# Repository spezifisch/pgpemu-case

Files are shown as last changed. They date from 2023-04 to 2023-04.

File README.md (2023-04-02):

# pgpemu gadget

A portable [pgpemu](https://github.com/spezifisch/pgpemu) gadget with >40h battery life and charger.

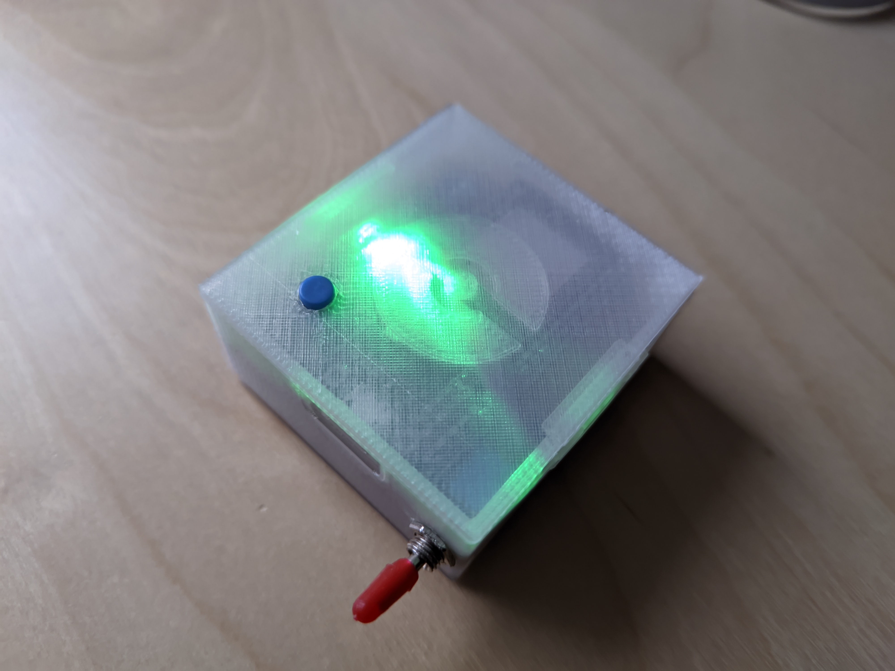
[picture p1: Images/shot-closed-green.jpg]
A 3D printed gadget with translucent plastic illuminated with a green LED


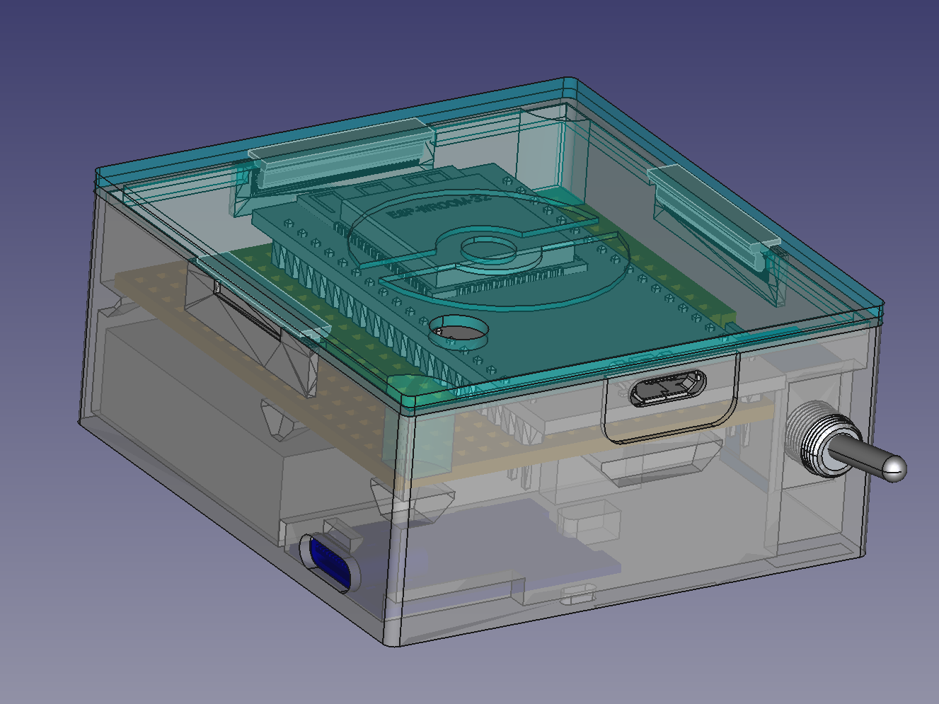
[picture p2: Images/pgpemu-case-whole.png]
3D model of the gadget in FreeCAD


## Usage

You can find the STL files in the `Output` directory.

When printing the bottom part make sure your slicer doesn't remove the thin wall around the ESP32 board's Micro USB port.

My print settings: 0.2mm layer height, 20% infill, transparent PLA.

See assembly notes at the end of this document.

## Development

Requirements:

- FreeCAD 0.20+
- [Assembly4](https://github.com/Zolko-123/FreeCAD_Assembly4)

The main file is `pgpemu_case.FCStd`.

### BOM

- ESP32 board: [ESP32 NODEMCU Module WiFi Development Board with CP2102](https://www.azdelivery.de/en/collections/nodemcu/products/esp32-developmentboard)
- Charger: [USB-C 5V 1A TP4056 Lithium Battery Charger Module](https://aliexpress.com/item/1005004654476348.html)
- LiPo battery: [EEMB 3.7V Lipo Battery 1800mAh 963450](https://www.aliexpress.com/item/1005003318811101.html) (make sure to get a good one with a protection circuit)
- generic toggle switch, 5mm RGB LED + resistors, push button with extension cap, standard silicon diode, 10µF electrolytic capacitor (on the perfboard, after the diode), 10µF SMD 0805 ceramic capacitor (directly on the ESP32 module between its power and ground pins)

## Perfboard

Here are some notes if you're interested to do a similar board. Drop me a mail and I will make you a schematic if you need it.

### LiPo Safety

The first **important** message is: **Do not charge the battery while the device is turned on!** You need extra circuitry to do it safely, which I haven't included because *in my use case* it's not something that I need to do. The device will not explode immediately (hopefully) but this is bad practice, see the reference links below. I see many projects in the wild doing this haphazardly and using LiPo batteries unsafely without knowing better. Be smart and consider using the resources below if you really need this feature. FYI if you see a project that doesn't address this they could be skimping on safety.

Here are some very important considerations when using a LiPo charger:

- <https://emariete.com/en/co2-meter-with-battery-well-done/>
- <https://www.best-microcontroller-projects.com/tp4056.html>
- <https://www.best-microcontroller-projects.com/dw01a.html>

### Supply

The ESP32 has an operating range from 3.0V - 3.6V (see [datasheet p.46](https://www.espressif.com/sites/default/files/documentation/esp32_datasheet_en.pdf)).

The LiPo battery that I chose has a safety circuit which ensures the voltage is >=3.0V and <=4.28V (see [datasheet section 6.1.0](https://ru.eemb.com/public/Download/Rechargeable-Lithium-Battery/Li-Polymer-Battery/Standard-Version/LP963450.pdf)) but the TP4056 charger only charges until 4.2V anyway. Also note that we're charging with 1A and the battery supports this according to the datasheet.

Now I considered generating the ESP32's voltage using either a boost regulator (battery -> boost 5V -> 3.3V with LDO on the ESP32 board), a modern LDO with 0.3V dropout voltage directly (battery -> LDO 3.3V) or just using a standard silicon diode I had lying around anyway to get the battery's range into the ESP32's range (battery -> diode drops 0.7V -> ESP32).

I went with the diode to reduce part count so I get between 2.3V and 3.5V which is safe for the ESP32. I haven't had any issues with this but in any case I added the mentioned 10µF caps.

Note that while you *can't* have the device switched on while charging, you *can* connect the ESP32's Micro USB while charging with the switch in the *off* position. Looking at the [ESP32 board schematic](https://cdn.shopify.com/s/files/1/1509/1638/files/ESP-32_NodeMCU_Developmentboard_Schematic_korr.pdf) the `AMS1117` output would be connected with your diode's cathode so you won't get backward currents into the battery or USB port.

## Assembly

At the bottom the TP4056 is tied down using a cable tie (otherwise USB-C plug action would be quite harsh on it). I isolated it sparing the LEDs for good measure.

The battery is glued to the bottom with a small piece of adhesive tape to keep it from flapping in the breeze. I also added a small piece of foam above the battery (not pictured) and some isolating tape covering the pointy parts of the board.

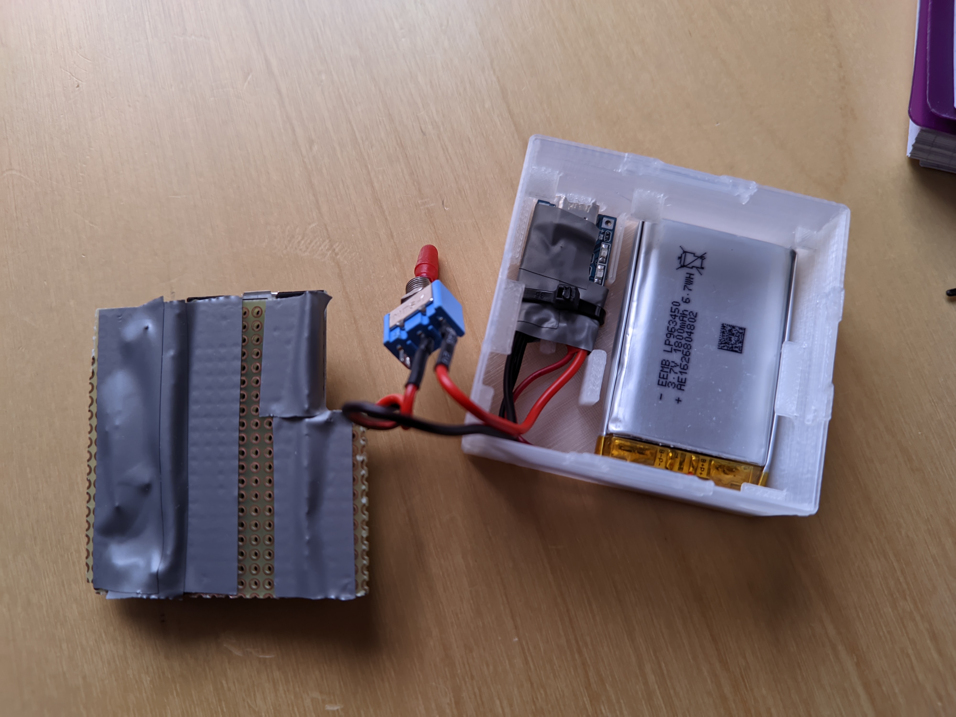
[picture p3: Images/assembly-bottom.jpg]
assembly bottom


The perfboard rests on top of that on the small holders at the sides.

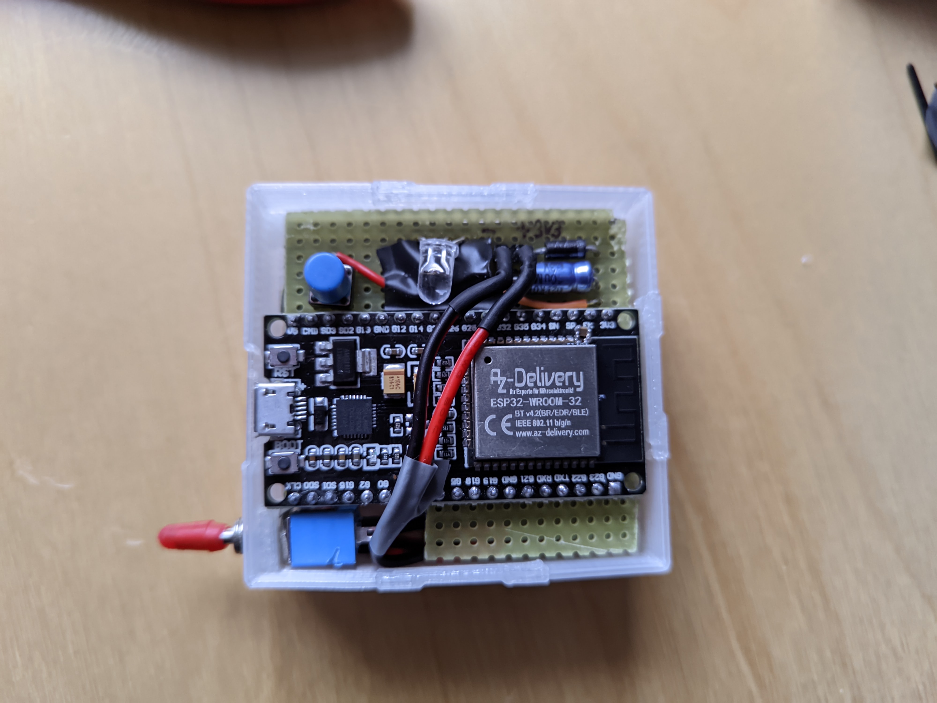
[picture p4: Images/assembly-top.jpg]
assembly top


The finished device, charging (while switched off, of course).

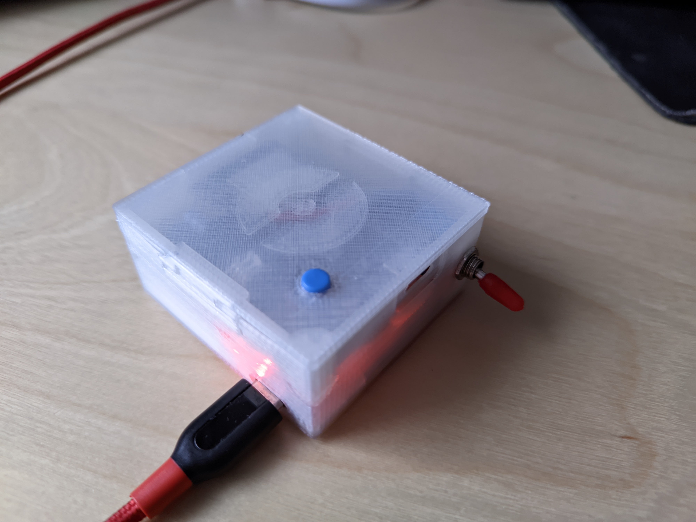
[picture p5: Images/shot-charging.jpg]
charging and glowing red with USB-C plugged in


Micro USB closeup: Access to serial console and bootloader.

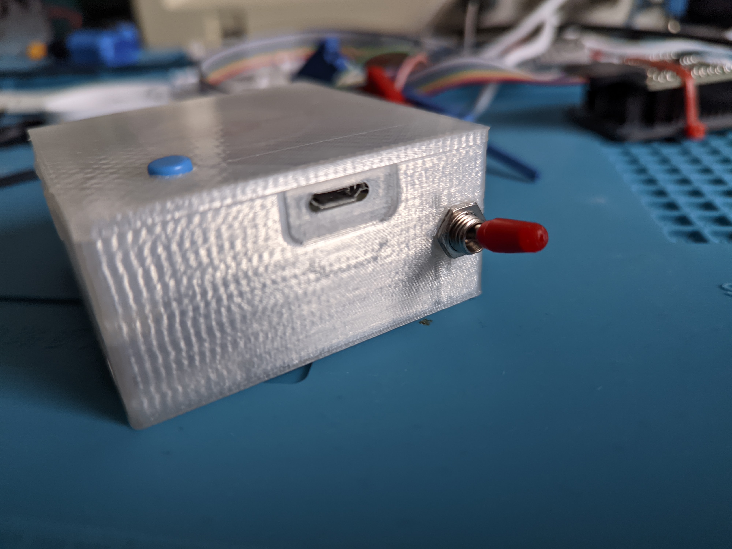
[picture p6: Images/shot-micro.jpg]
Micro USB port


USB-C closeup: Charger access.

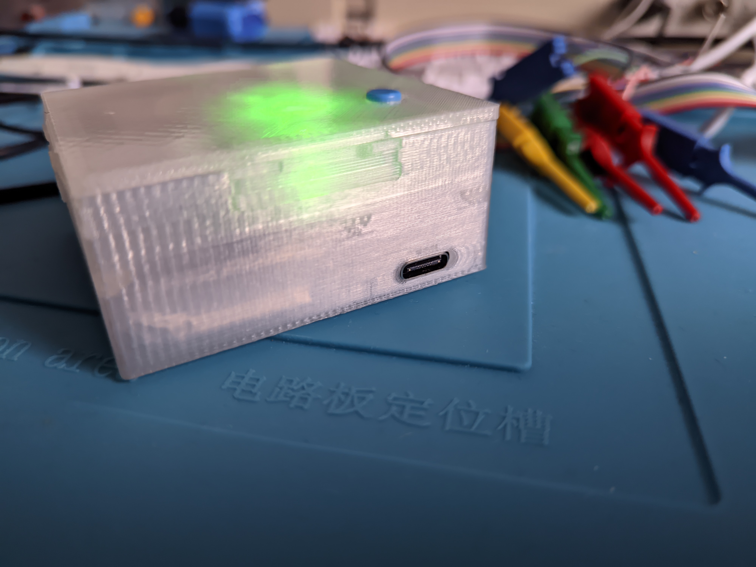
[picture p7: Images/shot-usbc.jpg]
USB-C port


## License

Unless otherwise stated my work in this repository is [CC BY-NC-SA 4.0](https://creativecommons.org/licenses/by-nc-sa/4.0/).

## Attributions

The following 3rd party parts with their own licenses are included.

### `Parts/PerfBoard`

I included the PerfBoard generator source for OpenSCAD with my settings, original:

> This thing was created by Thingiverse user Chunkmunk01, and is licensed under cc.

<https://www.thingiverse.com/thing:2054310>

### `Parts/PinHeader`

I included the PinHeader generator source for OpenSCAD with my settings, original:

> This thing was created by Thingiverse user karfes, and is licensed under cc.

<https://www.thingiverse.com/thing:2051023>

### `Parts/ESP32 DevKit C.FCStd`

ESP32 module and Micro USB port are from:

```text
ESP-WROOM-32

Raphael F. Martins
February 25th, 2020
WROOM-32 FEATURE
SW2018
```

<https://grabcad.com/library/esp-wroom-32-2>

### `Parts/TP4056 battery charger USB-C.*`

USB port is from:

> This thing was created by Thingiverse user Legacy_Micro, and is licensed under cc.

<https://www.thingiverse.com/thing:5745963>

### `Parts/spdt-print-toggle-switch`

Source:

```text
SPDT print toggle switch - PCB Mount

Chrismettal - Binary-6
February 19th, 2022
```

<https://grabcad.com/library/spdt-print-toggle-switch-pcb-mount-1>

### `Parts/Lid Hook.FCStd` and Bottom Receptacle

Source:

```text
ESP32 DevKit Case
by bkgoodman January 25, 2020
```

<https://www.thingiverse.com/thing:4125952>

As used in:

```text
ESP32 DevKit Case Wroom az-delivery 38 PIN
by tispokes April 21, 2022
```

<https://www.thingiverse.com/thing:5361695>

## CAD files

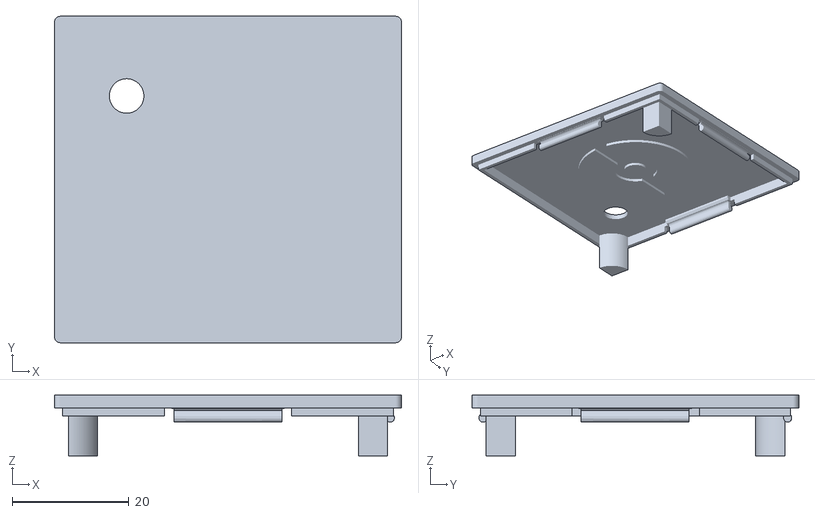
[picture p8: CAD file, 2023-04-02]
Output/pgpemu_case-ModelCase Lid.stl
59.4 x 55.9 x 10.4

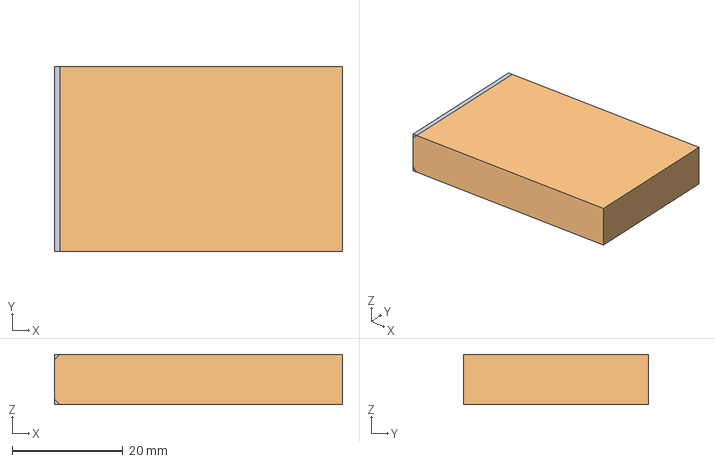
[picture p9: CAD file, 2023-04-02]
Parts/LiPo EEMB 963450.FCStd
52.0 x 33.4 x 9.10 mm

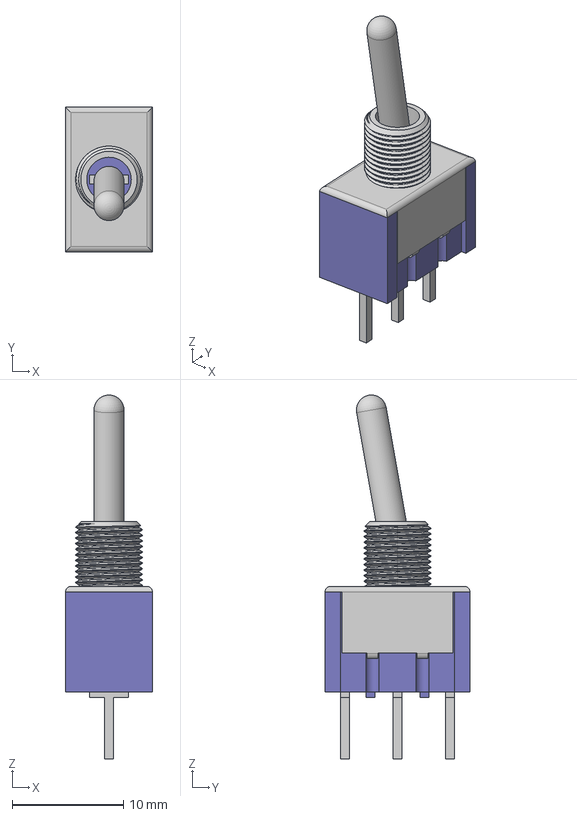
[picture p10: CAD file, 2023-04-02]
Parts/spdt-print-toggle-switch/SPDT-Print-Switch.step
7.80 x 13.0 x 32.7 mm
Plastic_Housing
Pin2
Pin1
Pin3
Shield
Shaft

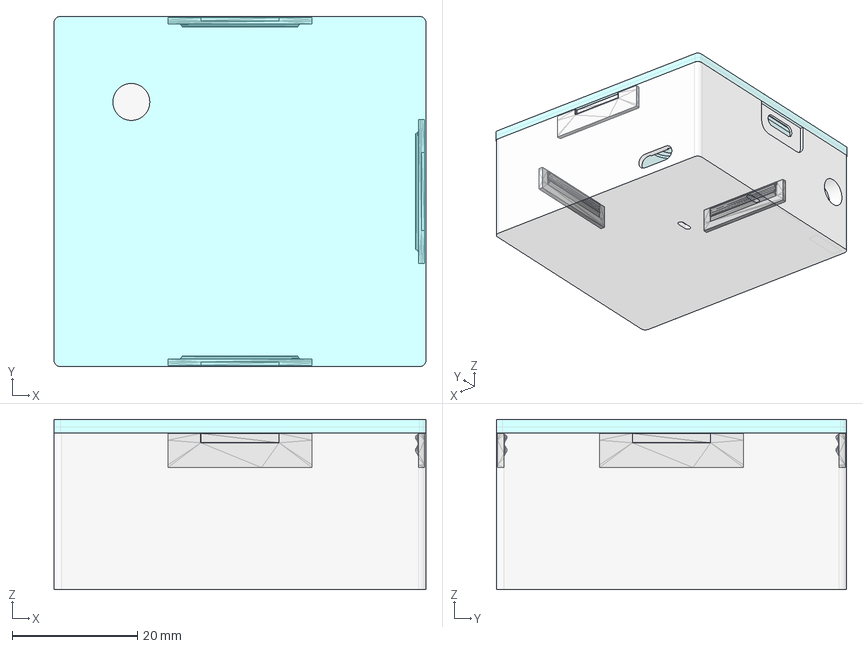
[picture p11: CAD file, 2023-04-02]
pgpemu_case.FCStd
59.4 x 55.9 x 27.2 mm
Lid Receptacle001
Lid Receptacle002
Lid Receptacle003
Lid Body

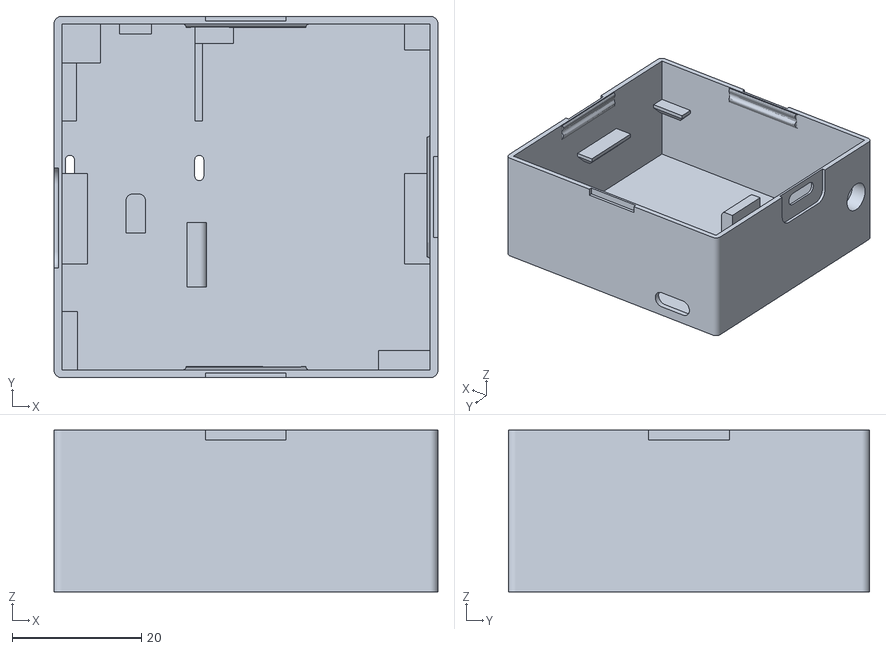
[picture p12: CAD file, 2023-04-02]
Output/pgpemu_case-ModelCase Bottom.stl
59.4 x 55.9 x 25.0

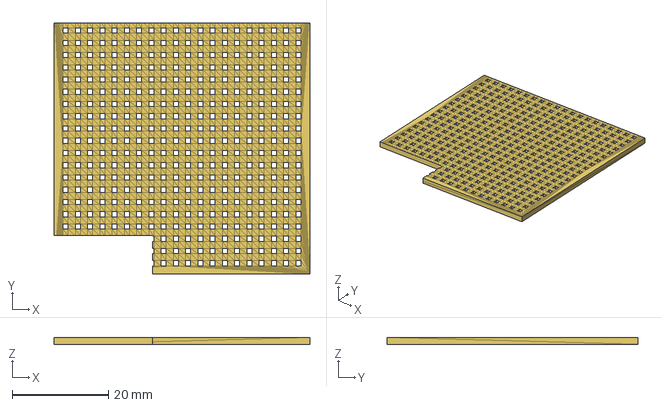
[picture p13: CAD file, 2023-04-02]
Parts/PerfBoard.FCStd
53.1 x 52.0 x 1.50 mm

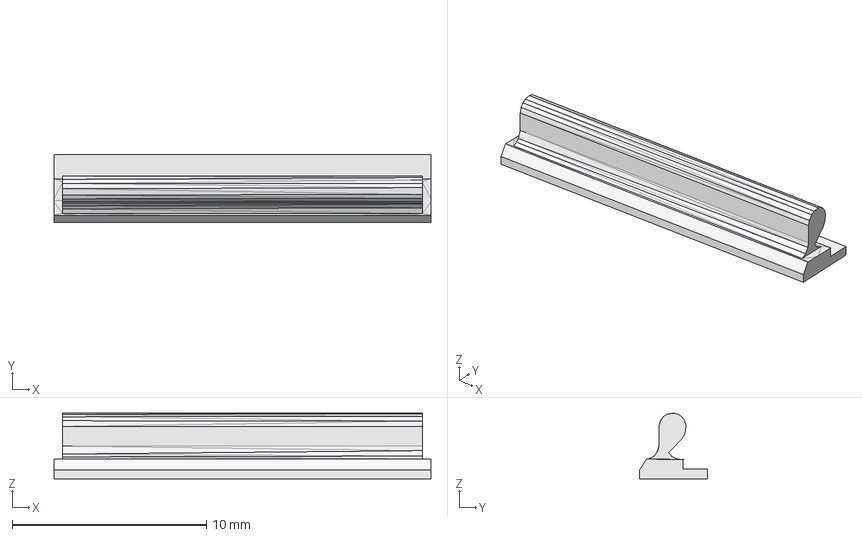
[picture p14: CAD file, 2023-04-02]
Parts/Lid Hook.FCStd
19.4 x 3.50 x 3.38 mm

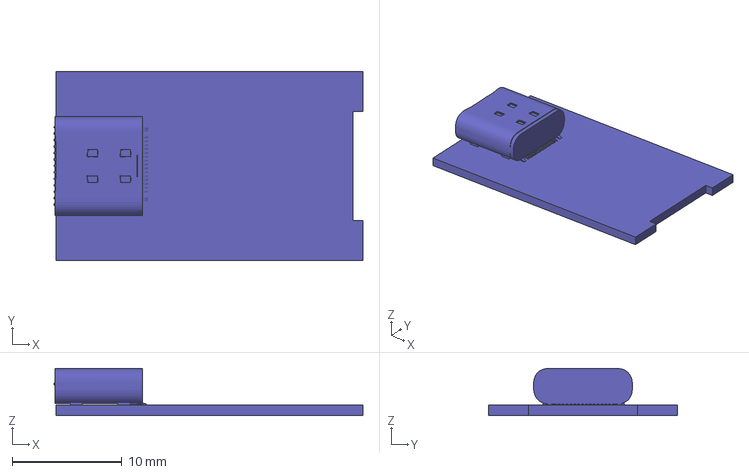
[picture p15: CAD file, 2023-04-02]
Parts/TP4056 battery charger USB-C.FCStd
28.1 x 17.2 x 4.30 mm

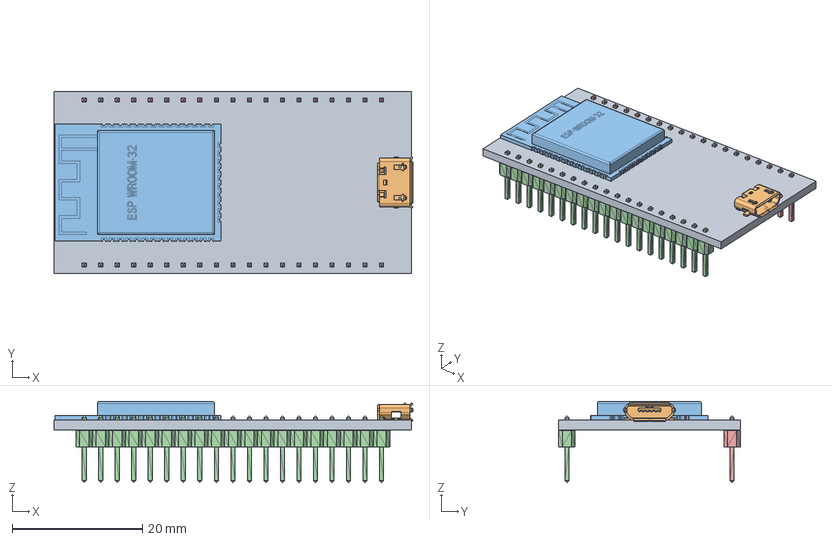
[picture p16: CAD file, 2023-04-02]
Parts/ESP32 DevKit C.FCStd
55.2 x 28.0 x 12.5 mm
PCB
Micro-USB x 2
ESP32 x 2
PinHeader1
PinHeader2

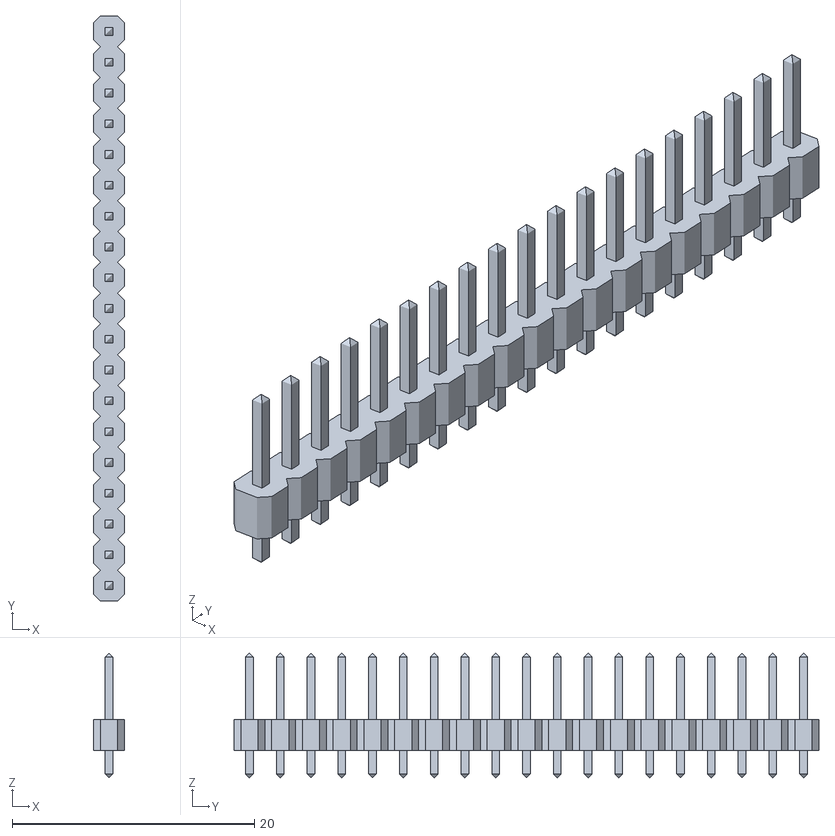
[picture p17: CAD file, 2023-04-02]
Parts/19 Pin Header 2.54mm.stl
2.54 x 48.3 x 10.3

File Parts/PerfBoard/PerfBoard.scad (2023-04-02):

/* 
Parametric Perfboard for electronics
with or without screw holes
*/


boardLength = 53.1; //Length in MM
boardWidth = 55.2; //Width in MM
boardThickness =1.5; //Thickness in MM
//Add screw holes (true or false)
screwHoles = 0; //[1:true,0:false]
screwHoleDiameter =  2.5; //Screw Hole Diameter

holesModuloX = (boardLength%2.54);
holesModuloY = (boardWidth%2.54);
holesLength = (boardLength-holesModuloX)/2.54;
holesWidth = (boardWidth-holesModuloY)/2.54;


boardLayout();
//throughHole();
//throughHoleLayout();

module boardLayout(){
    difference(){
        boardFlat();
        if (screwHoles==1)
            screwHolesLayout();
        throughHoleLayout();
    }
    dimensions();
}
module dimensions(){
    echo("Dimensions ",boardLength,"x",boardWidth,"x",boardThickness);
    echo("Hole Pattern ",holesLength,"x",holesWidth);
    if (screwHoles==1)
    echo("Screw Locations on center ", boardLength-screwHoleDiameter*6/4,"x",boardWidth-screwHoleDiameter*6/4);
}

module screwHolesLayout(){
    translate([0+screwHoleDiameter/4,0+screwHoleDiameter/4,0]) screwHole();
    translate([0+screwHoleDiameter/4,boardWidth-screwHoleDiameter*5/4,0]) screwHole();
    translate([boardLength-screwHoleDiameter*5/4,0+screwHoleDiameter/4,0]) screwHole();
    translate([boardLength-screwHoleDiameter*5/4,boardWidth-screwHoleDiameter*5/4,0]) screwHole();
    
}
module throughHoleLayout(){
    translate([holesModuloX/2,holesModuloY/2,0]){
        for (x = [1:holesLength]){
            for(y=[1:holesWidth]){
                translate([x*2.54-2.54/2,y*2.54-2.54/2,0]) throughHole();
            }
        }
    }
}


module boardFlat(){
    //translate([]);
    cube([boardLength,boardWidth,boardThickness]);
}
module throughHole(){
    translate([0,0,boardThickness/2]) rotate([0,0,45]) cylinder (d=1.5,h=boardThickness*2,center=true,$fn=4);
}
module screwHole(){
    translate([screwHoleDiameter/2,screwHoleDiameter/2,boardThickness/2]) cylinder(d=screwHoleDiameter,h=boardThickness*2,center=true,$fn=36);
}

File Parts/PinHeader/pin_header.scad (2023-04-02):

//Number of rows of pins in the header
header_rows = 19; //[1,2,3,4,5,6,7,8,9,10]

//Number of columns of pins in the header
header_columns = 1; //[1,2,3]

//The header's pitch between any two pins
header_pitch = 2.54; //[1.27,2.54]

header(header_rows,header_columns,header_pitch);

module header(rows,cols,pitch){
    offsety=-1*((rows-1)/2*pitch);
    offsetx=-1*((cols-1)/2*pitch);
    translate([offsetx,offsety,0])
    union(){
        for(j=[0:1:cols-1]){
            translate([pitch*j,0,0])
            for(i=[0:1:rows-1]){
                translate([0,pitch*i,0])pin(pitch);
            }
        }
    }
}

module pin(p=2.54){
    s=p/4+0.005;
    h=p*4-0.5;
    base=h/3;
    d=s/2;
    union(){
        color("gold")union(){
            translate([0,0,h+d])rotate([0,0,45])
            cylinder($fn=4,r1=sqrt(2*pow(d,2)),r2=0,h=d,center=false);
            translate([-d,-d,d])cube([s,s,h],center=false);
            translate([0,0,d])rotate([0,0,45])mirror([0,0,d])
            cylinder($fn=4,r1=sqrt(2*pow(d,2)),r2=0,h=d,center=false);
        }
       color("Dimgray")difference(){
            translate([0,0,base+d])cube([p,p,p],center=true);
            union(){
                translate([1.9*s,1.9*s,base+d])rotate([0,0,45])cylinder($fn=3,r=2*d,h=p+1,center=true);
                translate([1.9*s,-1.9*s,base+d-0.15])rotate([0,0,-45])cylinder($fn=3,r=2*d,h=p+1,center=true);
                translate([-1.9*s,-1.9*s,base+d-0.3])rotate([0,0,180+45])cylinder($fn=3,r=2*d,h=p+1,center=true);
                translate([-1.9*s,1.9*s,base+d-0.3])rotate([0,0,180-45])cylinder($fn=3,r=2*d,h=p+1,center=true);
            }
        }
    }
}

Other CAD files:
Parts/Prototype Board 1.FCStd
Parts/PerfBoard.stl
Parts/TP4056 battery charger USB-C.stl
Parts/spdt-print-toggle-switch/SPDT-Print-Switch.FCStd

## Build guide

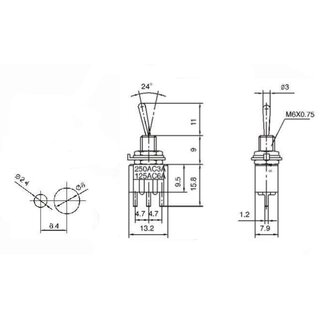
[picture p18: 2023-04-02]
Parts/spdt-print-toggle-switch/SPDT-Print-Switch-Schematic.jpg

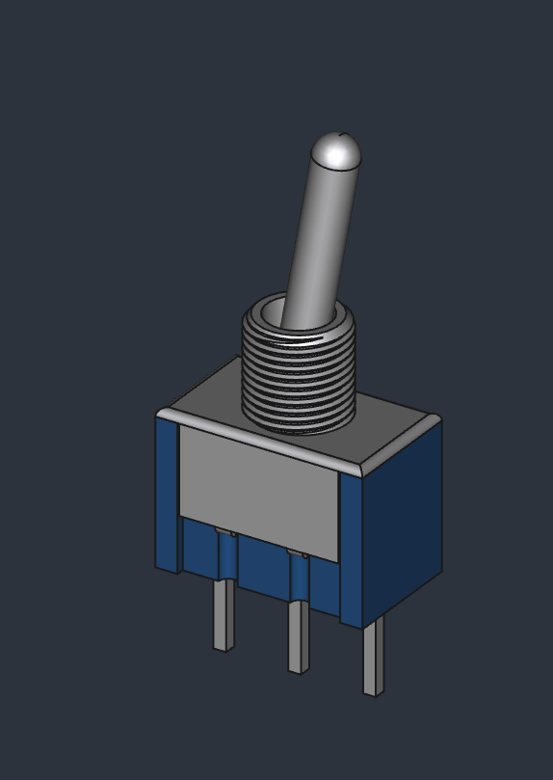
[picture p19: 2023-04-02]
Parts/spdt-print-toggle-switch/SPDT-Print-Switch.png

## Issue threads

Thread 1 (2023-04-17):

Can we create virtual Go+?

DineshValor, 2023-04-17:
Saw many platforms which provide virtual pokemon go plus as mod app or injector via root such as iPogo, Pgsharp but they took charges monthly and I haven't much money to buy there plans.
So, I'm looking to create own Virtual Go Plus.
Can someone help me.

spezifisch, 2023-04-17:
Emulating a Go Plus on the Android side should be possible as an [LSPosed](https://github.com/LSPosed/LSPosed) module. I can give you some pointers where to start but I'm not personally interested in implementing this. This will definitely take a lot of work and I can't assist you with all the steps.

You need to find out which Android API functions Pokemon Go calls to communicate with the Go+. As the Go+ implements a GATT server it will need to be at least most of the functions listed here:

* https://developer.android.com/guide/topics/connectivity/bluetooth/find-ble-devices
* https://developer.android.com/guide/topics/connectivity/bluetooth/connect-gatt-server
* https://developer.android.com/guide/topics/connectivity/bluetooth/transfer-ble-data

I think your best bet would be to hook all of those functions and log the communication between Pokemon Go and a real Go+. Maybe for Bluetooth scan and service discovery you can simply "replay" most of the answers the API gives.

Once Pokemon Go thinks it's connected go a Go Plus, emulating the Go Plus' responses should be the easier part. You can base that on the [pgpemu code](https://github.com/spezifisch/pgpemu/tree/9e48266c9d7bcc5f63986548121d490d0fb62a2c/pgpemu-esp32/main), most of the files beginning with `pgp_` will need to be ported for this. Or maybe you can get them to compile using [NDK](https://developer.android.com/ndk) and use them from your LSPosed module with some glue in between.

DineshValor, 2023-04-17:
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

Thanks for all information, I'm definitely gonna make it possible and try it again n again untill succeeded.

I know only little bit coding, that's why getting trouble to  create virtual Go+.

DineshValor, 2023-04-17:
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

Fiest thanks for all information but i can't make it bcoz it's something like that is impossible task for me who don't even idea from where to start and how.

DineshValor, 2023-04-19:
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

I have previously saved one app which simulate Go+ with root access but unfortunately not supported Android 12+, also update of this app become paid.
App Link
https://drive.google.com/file/d/1mdeavfopaFnuU2UBwFg_0ClD98c95VJq/view?usp=drivesdk

Can you extract Go+ files from it and make it LSposed module or root based app?
Also we ready to fund you in respect of your time spend and effort.
Please help us to make Virtual Go+ 🙏

Closed 2023-04-20.
